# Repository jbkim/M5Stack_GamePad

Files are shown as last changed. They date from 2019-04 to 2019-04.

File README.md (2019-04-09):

# M5Stack_GamePad
### M5Stack용 Gamepad
- I2C 디바이스로 동작함
- M5Stack의 I2C포트에 연결이 되어 조이스틱의 값 및  버튼입력 값을 받을 수 있다.
- M5Stack용 Joystck과 사용법이 같다. https://docs.m5stack.com/#/en/unit/joystick
- 차이점은
    - requestFrom 함수의 인자값을 3 대신 4로 입력한다.
    - 키 버튼의 맵핑은 
    ```cpp
        void loop() {
        // put your main code here, to run repeatedly:
        Wire.requestFrom(JOY_ADDR, 4);
        if (Wire.available()) {
            x_data = Wire.read();
            y_data = Wire.read();
            select_data = Wire.read(); // Joystick button
            btn_data = Wire.read();    // Keypad button: up, down, left, right
                
            sprintf(data, "x:%d y:%d button:%d\n", x_data, y_data, select_data);
            Serial.print(data);

            if (btn_data & UP) Serial.println("UP");
            if (btn_data & DOWN) Serial.println("DOWN");
            if (btn_data & LEFT) Serial.println("LEFT");
            if (btn_data & RIGHT) Serial.println("RIGHT");                
        }
        delay(200);
        }
    ```

- History
    - Version 1.0
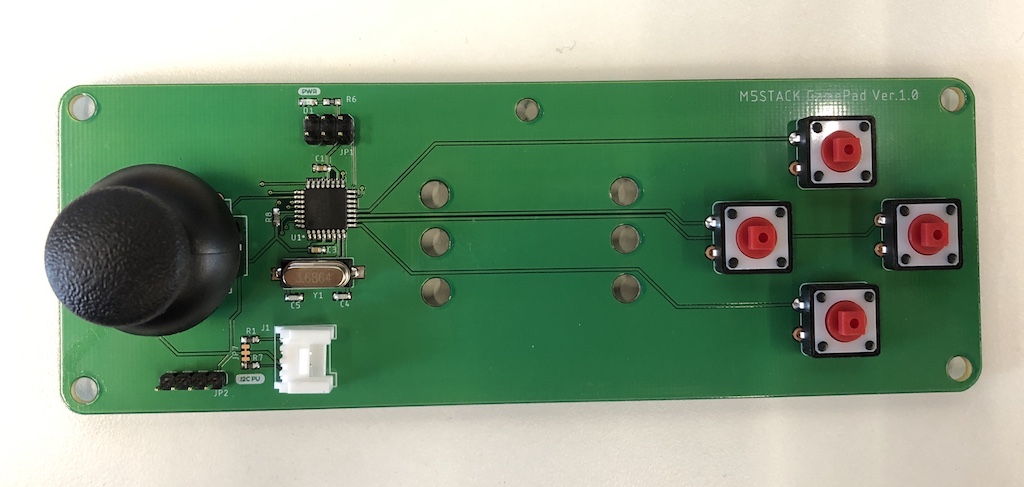
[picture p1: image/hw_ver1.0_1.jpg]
        
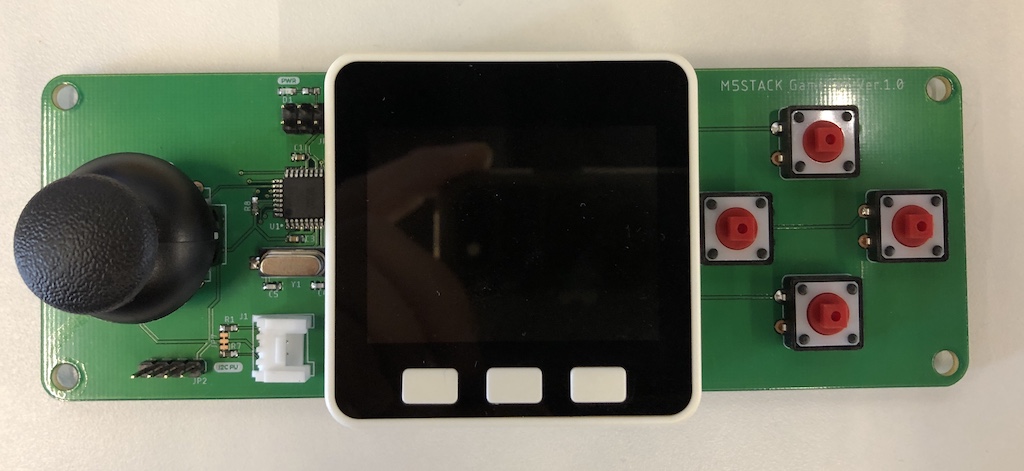
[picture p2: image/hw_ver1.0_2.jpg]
        
    - Version 1.1
        - I2C 포트의 위치 변경
        - 홀 사이즈 변경
        - PCB 레이아웃 변경

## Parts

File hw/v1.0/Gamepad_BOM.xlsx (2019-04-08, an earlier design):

 | GamePad BOM |  |  |  |  | 2019-02-18
 | Parts Reference | Value | Device | Package | Qty | Description
1 | JP2 |  | Pin header 2.54 pitch | 1X04 | 1
2 | JP1 |  | Pin header 2.54 pitch | 2X03 | 1
3 | C1, C3 | 0.1uF | Chip Capacitor (16V, J급) | 1608 | 2
4 | R8 | 10K | Chip Resistor (J급) | 1608 | 1
5 | R6 | 1k | Chip Resistor (J급) | 1608 | 1
6 | R1, R7 | 2.2K | Chip Resistor (J급) | 1608 | 2
7 | C4, C5 | 20pF | Chip Capacitor (16V, J급) | 1608 | 2
8 | Y1 | 3.6864Mhz (20pF) | Crystal SMD | HC49UP | 1 | http://www.devicemart.co.kr/goods/view?no=5267
9 | J1 | 4P-2.0-90D | Grove Connector | HW4-2.0-90D | 1 | https://www.digikey.com/product-detail/en/seeed-technology-co-ltd/110990037/1597-1083-ND/5482561
10 | U1 | ATMEGA328P-AU | ATMEGA328P-AU | TQFP32 | 1
11 | S1 |  | Analog JOYSTICK |  | 1 | http://www.icbanq.com/P006963674
12 | D1 | RED | Chip LED SMD | 1608 | 1
13 | S2, S3, S4, S5 | SWITCH-MOMENTARY-212MM | SWITCH-MOMENTARY-212MM | TACTILE-PTH-12MM | 4 | http://www.icbanq.com/P001429346

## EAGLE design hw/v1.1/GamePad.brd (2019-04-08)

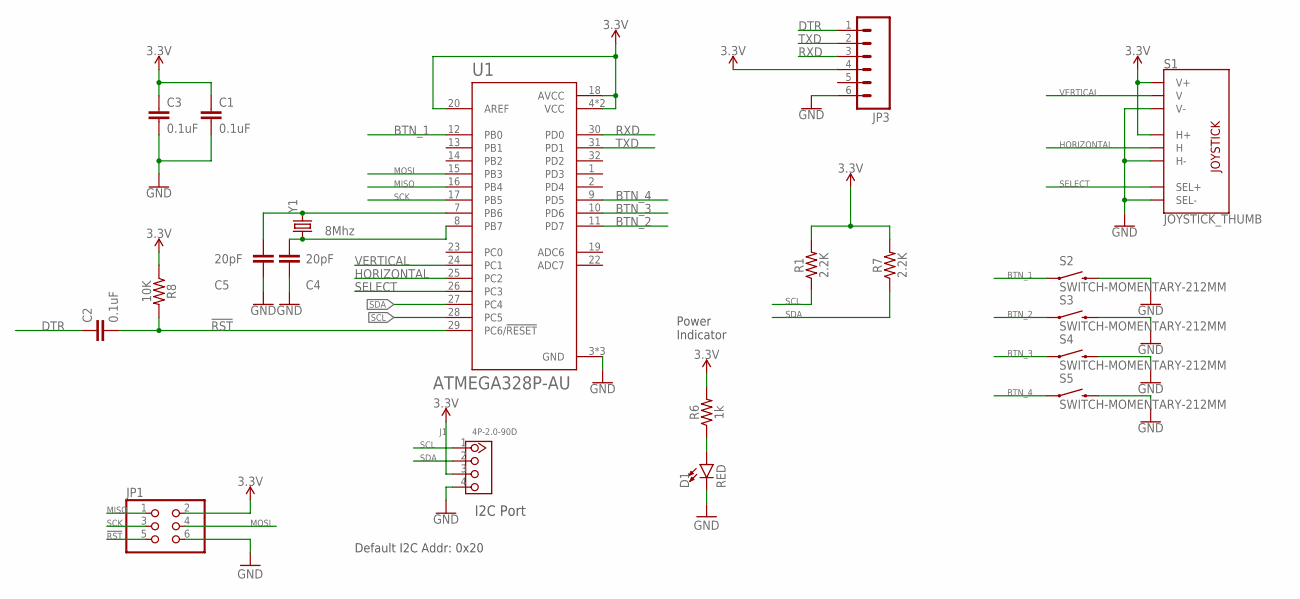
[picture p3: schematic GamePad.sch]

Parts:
C1, C2, C3: 0.1uF; 0603-CAP
C4, C5: 20pF; 0603-CAP
D1: RED; LED-0603
J1: 4P-2.0-90D; HW4-2.0-90D
JP1: PINHD-2X3; 2X03
JP3: M06LOCK; 1X06_LOCK
R1, R7: 2.2K; 0603
R6: 1k; 0603
R8: 10K; 0603
S1: JOYSTICK_THUMB; JOYSTICK
S2, S3, S4, S5: SWITCH-MOMENTARY-212MM; TACTILE-PTH-12MM
U1: ATMEGA328P-AU; QFP80P900X900X120-32N
Y1: 8Mhz; HC49UP

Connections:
3.3V: C1.1, C3.1, J1.3, JP1.2, JP3.4, R1.2, R6.2, R7.2, R8.1, S1.H1 (H+), S1.V1 (V+), U1.4 (VCC), U1.6 (VCC), U1.18 (AVCC), U1.20 (AREF)
!RST: C2.2, JP1.5, R8.2, U1.29 (PC6/!RESET)
BTN_1: S2.1, U1.12 (PB0)
BTN_2: S3.1, U1.11 (PD7)
BTN_3: S4.1, U1.10 (PD6)
BTN_4: S5.1, U1.9 (PD5)
DTR: C2.1, JP3.1
GND: C1.2, C3.2, C4.1, C5.1, D1.C, J1.4, JP1.6, JP3.6, S1.B2A (SEL-), S1.H3 (H-), S1.V3 (V-), S2.3 (2), S3.3 (2), S4.3 (2), S5.3 (2), U1.3 (GND), U1.5 (GND), U1.21 (GND)
HORIZONTAL: S1.H2 (H), U1.25 (PC2)
MISO: JP1.1, U1.16 (PB4)
MOSI: JP1.4, U1.15 (PB3)
unnamed: D1.A, R6.1
unnamed: C5.2, U1.7 (PB6), Y1.2
unnamed: C4.2, U1.8 (PB7), Y1.1
RXD: JP3.3, U1.30 (PD0)
SCK: JP1.3, U1.17 (PB5)
SCL: J1.1, R1.1, U1.28 (PC5)
SDA: J1.2, R7.1, U1.27 (PC4)
SELECT: S1.B1A (SEL+), U1.26 (PC3)
TXD: JP3.2, U1.31 (PD1)
VERTICAL: S1.V2 (V), U1.24 (PC1)

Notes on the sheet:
Power Indicator
I2C Port
Default I2C Addr: 0x20

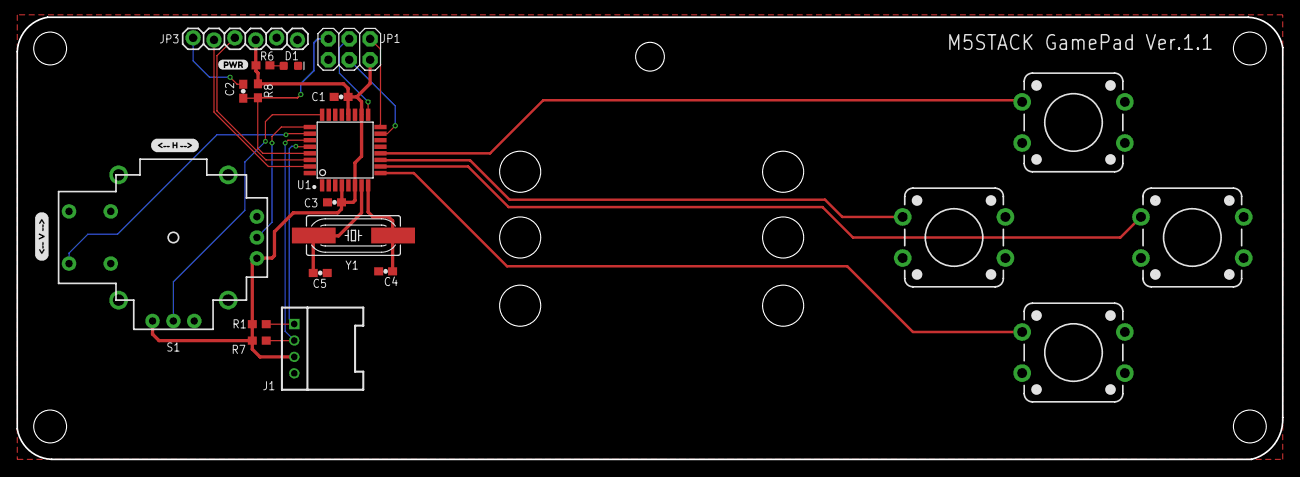
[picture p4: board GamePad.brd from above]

Board: 2 copper layers, 154.0 x 53.8 mm, 23 parts (0 on the bottom side), 21 nets.

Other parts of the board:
U$7: ###_V_###0
U$14: PWR-()-03
U$15: ###_H_###1

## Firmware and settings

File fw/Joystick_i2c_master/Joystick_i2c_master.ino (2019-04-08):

#include <M5Stack.h>
#include "Wire.h"

#define JOY_ADDR 0x52

#define UP    1
#define DOWN  2
#define LEFT  4
#define RIGHT 8

void setup() {
  M5.begin();
  M5.Lcd.clear();
  //disable the speak noise
  dacWrite(25, 0);

  Wire.begin(21, 22, 400000);
}

uint8_t x_data;
uint8_t y_data;
uint8_t select_data;
uint8_t btn_data;

char data[100];

void loop() {
  // put your main code here, to run repeatedly:
  Wire.requestFrom(JOY_ADDR, 4);
  if (Wire.available()) {
    x_data = Wire.read();
    y_data = Wire.read();
    select_data = Wire.read();
    btn_data = Wire.read();
        
    sprintf(data, "x:%d y:%d button:%d\n", x_data, y_data, select_data);
    Serial.print(data);

    if (btn_data & UP) Serial.println("UP");
    if (btn_data & DOWN) Serial.println("DOWN");
    if (btn_data & LEFT) Serial.println("LEFT");
    if (btn_data & RIGHT) Serial.println("RIGHT");                
  }
  delay(200);
}

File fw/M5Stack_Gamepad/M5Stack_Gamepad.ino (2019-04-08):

#include <Wire.h>

#define I2C_ADDR  0x52

#define VERTICAL    A1
#define HORIZONTAL  A2
#define SELECT      A3 

#define UP      8 
#define DOWN    5
#define LEFT    7
#define RIGHT   6

byte X_Pot, Y_Pot;
byte Select_state;
byte Button_state;
volatile byte recvAddr; 

//Turn on interrupt for the button
void setupInterrupts()
{
  attachInterrupt(digitalPinToInterrupt(SELECT), buttonInterrupt, CHANGE);  
}

//Called any time the pin changes state
void buttonInterrupt()
{
//  if (digitalRead(SELECT) == LOW) 
//  {
//    Select_state = 0;
//  }else  {
//    Select_state = 1;
//  }
}

void updateJoystick() 
{
  int tmp;
//  byte btn;

  // swap x & y
  // mapping
  tmp = analogRead(VERTICAL);
  X_Pot = map(tmp, 0, 1023, 0, 255);  
  tmp = analogRead(HORIZONTAL);
  Y_Pot = map(tmp, 0, 1023, 0, 255);  

  Select_state = digitalRead(SELECT);

  // read button
  Button_state = 0;
  Button_state = digitalRead(UP);
  Button_state |= digitalRead(DOWN) << 1;
  Button_state |= digitalRead(LEFT) << 2;
  Button_state |= digitalRead(RIGHT) << 3; 
  Button_state |= 0xF0; 
  Button_state = ~Button_state;
  
} 


void receiveEvent(int numberOfBytesReceived)
{
  recvAddr = Wire.read();

  for (byte x = 0 ; x < numberOfBytesReceived - 1 ; x++)
  {
    byte c = Wire.read(); 
    Serial.print(c);
  }
}


//Respond to GET commands
void requestEvent()
{
  updateJoystick();
//  Select_state = digitalRead(SELECT);

  Wire.write(X_Pot);
  Wire.write(Y_Pot);
  Wire.write(Select_state);
  Wire.write(Button_state);  
}

void setup() {
  pinMode(LED_BUILTIN, OUTPUT);
    
  pinMode(SELECT, INPUT_PULLUP);
  pinMode(UP, INPUT_PULLUP);
  pinMode(DOWN, INPUT_PULLUP);
  pinMode(LEFT, INPUT_PULLUP);
  pinMode(RIGHT, INPUT_PULLUP);

  setupInterrupts(); //Enable pin change interrupts for I2C and button

  Wire.begin(I2C_ADDR); //Start I2C and answer calls using address from EEPROM

  //The connections to the interrupts are severed when a Wire.begin occurs. So re-declare them.
  Wire.onReceive(receiveEvent);
  Wire.onRequest(requestEvent);

//  digitalWrite(SELECT, HIGH);
  Serial.begin(115200);

//  digitalWrite(LED_BUILTIN, HIGH);
//  delay(500);
//  digitalWrite(LED_BUILTIN, LOW);
//  delay(500);                       
}
 
void loop() {

  updateJoystick();
  
  Serial.print("X-axis: ");
  Serial.println(X_Pot);
  Serial.print("Y-axis: ");
  Serial.println(Y_Pot);
  Serial.print("Select:  ");
  Serial.println(Select_state);
  Serial.print("Button:  ");
  Serial.println(Button_state, BIN);

  if (Button_state & 0x01) Serial.println("UP");
  if (Button_state & 0x02) Serial.println("DOWN");
  if (Button_state & 0x04) Serial.println("LEFT");
  if (Button_state & 0x08) Serial.println("RIGHT");                


  delay(200);                      
}

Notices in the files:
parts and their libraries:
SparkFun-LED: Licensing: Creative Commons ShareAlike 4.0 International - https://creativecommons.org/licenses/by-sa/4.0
